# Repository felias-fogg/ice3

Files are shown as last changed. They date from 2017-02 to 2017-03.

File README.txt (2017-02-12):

This Arduino sketch implements a cache thermometer, as for example
used in these geocaches:
- http://coord.info/GC3NEYY
- http://coord.info/GC47429
- http://coord.info/GC36NCQ

The generic hardware is sketched in the files open-V2-board.tiff and 
open-V2-plan.tiff. For the particular case of a thermometer, a DS18S20
and a LED is added in the prototyping section of the board. 

In order to compile and burn the sketch to the ATtiny84, one has to
make a few additions and modifications to the Arduino IDE and one
either has to use an existing UNO board as an ISP programmer or one
has to buy such a programmer, e.g., a USBtinyISP, see
http://www.amazon.com/HOSSEN%C2%AE-USBtinyISP-Programmer-Arduino-Bootloader/dp/B00CR9UGZQ/ref=sr_1_5.

First of all, one needs to extend the Arduino IDE to deal with
ATtiny processors. This is described in detail here:
http://hlt.media.mit.edu/?p=1695.

In order to compile the ice3 sketch, you need the OneWire
library. Note that the original library will not work here, because we
want the ATtiny to run with 1MHz. So download and install this library instead: https://github.com/felias-fogg/OneWire.

Now you should be able to compile the sketch. Please select ATtiny84
(internal 1 MHz) before doing so. By the way, if the ATtiny has been
used before, perhaps some fuses have to be set. In particular the one
for the processor speed. This can be done by pretending to upload the
bootloader. If it is a brand new processor or the one from an existing
ice3 board, the fuses will have been set to 1 MHz already.

Finally, you should be able to burn the program to the chip. Before
doing so remove the jumper that provides power to the board.  Plug the
6-pin ISP connector to the PCB such that the nose of the connector is
oriented towards the battery. Select the right programmer in the Tools
menu and select also the right serial port. Then you can use the
upload button to burn the program to the chip.

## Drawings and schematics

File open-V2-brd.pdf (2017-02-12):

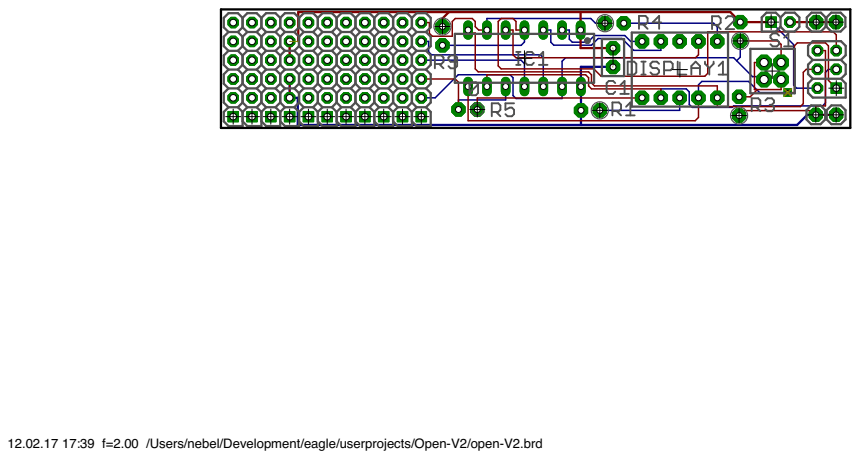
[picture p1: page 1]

12.02.17 17:39 f=2.00 /Users/nebel/Development/eagle/userprojects/Open-V2/open-V2.brd

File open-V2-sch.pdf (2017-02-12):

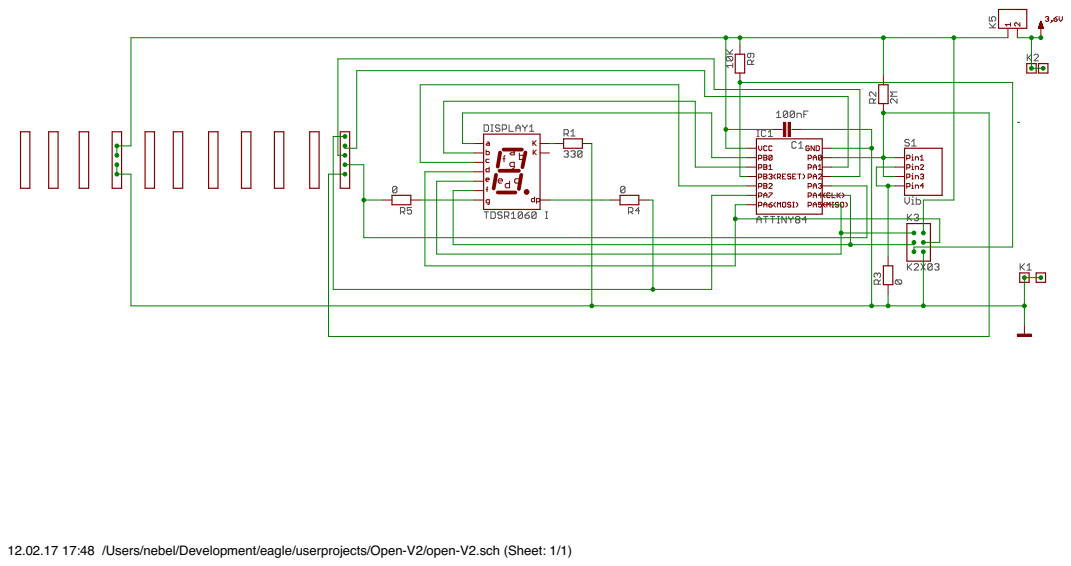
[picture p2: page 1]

12.02.17 17:48 /Users/nebel/Development/eagle/userprojects/Open-V2/open-V2.sch (Sheet: 1/1)

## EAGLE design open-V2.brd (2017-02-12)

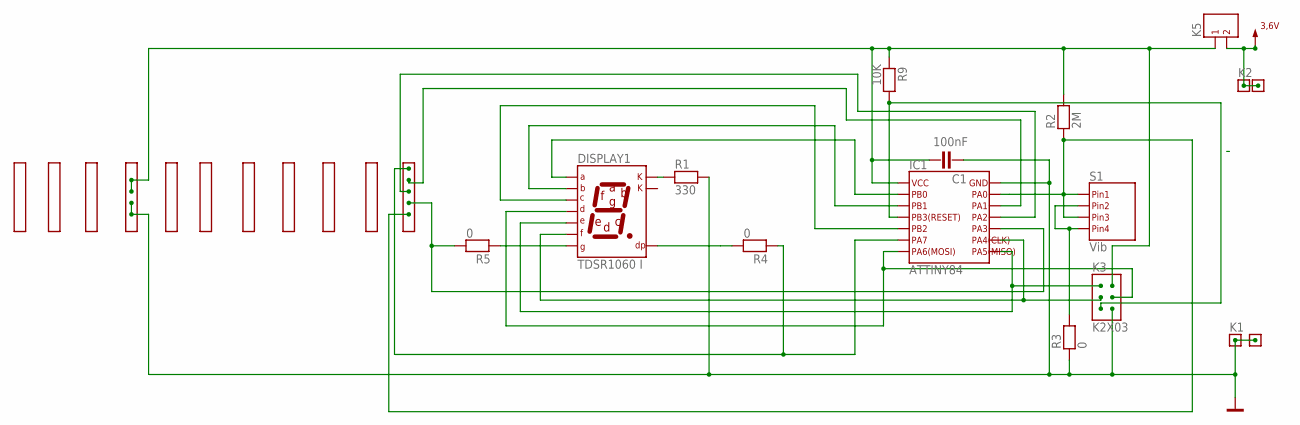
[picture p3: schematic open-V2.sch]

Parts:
C1: 100nF; C1
DISPLAY1: TDSR1060 I; DISPLAY1
IC1: ATTINY84; IC1
K1: K1
K2: K2
K3: K2X03; K3
K4: K4
K5: K5
K6: K6
K7: K7
K8: K8
K9: K9
K10: K10
K11: K11
K12: K12
K13: K13
K14: K14
K15: K15
K16: K16
K18: K18
R1: 330; R1
R2: 2M; R2
R3: 0; R3
R4: 0; R4
R5: 0; R5
R9: 10K; R9
S1: Vib; S1

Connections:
1: DISPLAY1.1 (G), R5.1
3,6V: K2.1, K5.2, K18.1
A: DISPLAY1.10 (A), IC1.2 (PB0)
B: DISPLAY1.9 (B), IC1.3 (PB1)
C: DISPLAY1.7 (C), IC1.5 (PB2)
D/MOSI: DISPLAY1.5 (D), IC1.7 (PA6(MOSI)), K3.4
DP: DISPLAY1.6 (DP), R4.2
E/MISO: DISPLAY1.4 (E), IC1.8 (PA5(MISO)), K3.1
F/CLK: DISPLAY1.2 (F), IC1.9 (PA4(CLK)), K3.3
G: IC1.10 (PA3), K10.3, R5.2
GND: C1.1, IC1.14 (GND), K1.1, K3.6, K13.2, K13.3, K16.1, R1.2, R3.1
K: DISPLAY1.3 (K), R1.1
PA0: IC1.13 (PA0), K10.2, R2.1, S1.1 (PIN1), S1.3 (PIN3)
PA1: IC1.12 (PA1), K10.5
PA2: IC1.11 (PA2), K10.4
PA7: IC1.6 (PA7), K10.6, R4.1
RST: IC1.4 (PB3(RESET)), K3.5, R9.2
SIG$25: R3.2, S1.2 (PIN2), S1.4 (PIN4)
VCC: C1.2, IC1.1 (VCC), K3.2, K5.1, K13.4, K13.5, R2.2, R9.1

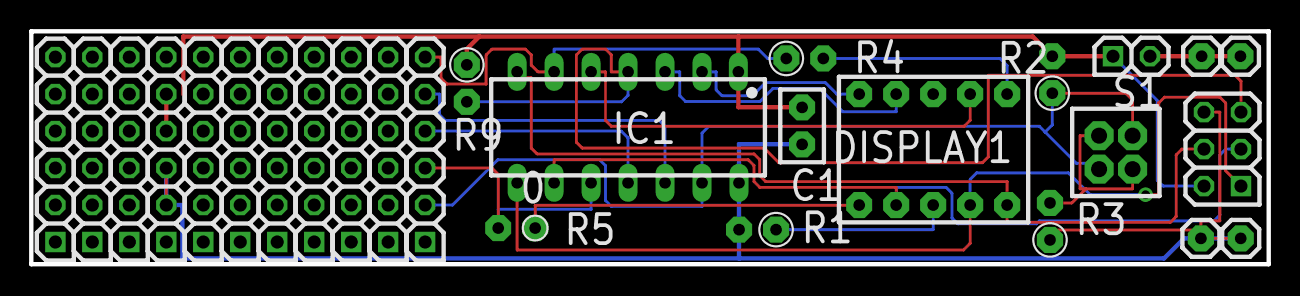
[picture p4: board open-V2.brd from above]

Board: 2 copper layers, 85.0 x 16.0 mm, 27 parts (0 on the bottom side), 19 nets.

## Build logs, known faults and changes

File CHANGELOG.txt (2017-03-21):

Version 3 - 22.8.2013
	- Version that is working in the Cache "Geocache on the Rocks"

Version 3.1 - 5.10.2013
       - new flag for switching between Celsius and Fahrenheit in EEPROM

Version 3.4 - 21.3.1017
      - added  __attribute__((used)) to wdt_init

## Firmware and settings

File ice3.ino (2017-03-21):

// -*- c++ -*-
// Developed on a Pro Mini, deployed on an Attiny84

#include <avr/pgmspace.h>
#include <avr/wdt.h>
#include <avr/sleep.h>
#include <avr/eeprom.h>
#include <OneWire.h>

// CHANGE NEXT LINES! ************************************************
const char show_string[] = "N 44# 43.541  W 63# 44.270    ";
#define DEFAULT_SYSTEM_CELCIUS 0xFF // 0xFF means celcius is default 
#define TEMP_THRESH 4.0 // degrees Celcius
// END OF CHANGE *********************************************************

#define VERSION "Version 3.4" 

uint8_t celcius[1] EEMEM; // flag for celcius or fahrenheit (default celcius = 0xFF)
uint8_t coords[30] EEMEM; // coord string - will be loaded from default show_string

#define DEBUGVOLT 1
#define DEBUGWAIT
#define COORDSHOW 6 // show coords this number of times
#define PCBVERSION 3 // can be 0: no DS18S20, 1 or 2 : open-vX board, 3: open-v2
#define ERROR_THRESH 5 // after this many errors, we give up

/* display times */
#define DISPLAY_ON_MSECS 800 // msecs on
#define DISPLAY_OFF_MSECS 300 // msecs off
#define LONGDEEPSLEEP_SECS 40 // have a deep sleep after displaying coords
#define SHORTDEEPSLEEP_SECS 10 // after batt lo
#define MAX_NOCHANGE_MSECS 240000UL // msecs without change leads to sleep
#define MAX_ACTIVE_MSECS  2400000UL // 30 minutes max on!
#define MAX_WAKEUP_MSECS 20000UL // msecs to wake up!
#define MIN_BUMPS 4 // minimum of 4 bumps before complete wakeup
#define READY_MAX 3 // show temp after reaching threshold
#define LOWVOLT_WARN 2.9
#define LOWVOLT_ERROR 2.6 // below this, we only show "Lo Batt"
#define LOWBATTSHOW_MSECS 30000UL // show Low-Batt message for this number of msecs


#if PCBVERSION == 3 // same version of board as 2, but LED and DS18S20 switched
#define DS18S20 2
#define VPINSEGG 7
#define VPINLED 1
#define VOLTOFFSET 0.0
#define TEMPTOLERANCE 0.0
#endif
#if PCBVERSION == 2 // new version of board
#define DS18S20 1
#define VPINSEGG 7
#define VPINLED 2
#define VOLTOFFSET 0.0
#define TEMPTOLERANCE 0.0
#endif
#if PCBVERSION == 1 // old version of board
#define DS18S20 1
#define VPINSEGG 2
#define VPINLED 7
#define VOLTOFFSET 0.0
#define TEMPTOLERANCE 0.0
#endif
#if PCBVERSION == 0 // PCB without temperature sensor
#define VPINLED 7
#define VPINSEGG 1
#define VOLTOFFSET -0.2
// needed for calibrating the internal temp sensor
#define TOS -244
#define BANDGAPVAR 5
#define TEMPSCALE 0.7068
#define TEMPTOLERANCE 2.0
#endif

#ifdef __AVR_ATmega328P__
#define POFF 2
#define ATMEGA 1
#define T1_vect TIMER1_OVF_vect
#define PCINT_vect PCINT1_vect
#else
#define POFF 0
#define ATTINY 1
#define T1_vect TIM1_OVF_vect
#define PCINT_vect PCINT0_vect
#endif


/* Connections auf open-v1 (proto area to the left)
   Put in: R1, R2, R3, R9, C1, ISP, jumper connector
   Put in: IC1 Punkt/Kerbe Richtung ISP-Stecker
   Put in: Display D1 with dot towards IC
   Brücke von R4 unten nach erste Reihe Pin 3/4
   Connection from 5/6 to middle pin of DS1820
   4,7K from pin 2 of DS1820 to VCC
   Pin 1 of DS1820 to GND, pin 3 to VCC
*/
/* Display
   Seg	AVR-Pin Ard#(Attiny) Ard#(ProMini)
   a(10) -  PA6   6          8
   b(9)  -  PA5   5          7
   c(7)  -  PA4   4          6
   d(5)  -  PB0  10         12
   e(4)  -  PB1   9         11
   f(2)  -  PB2   8         10
   g(1)  -  PA2   2          4
   dp(6) -  PA3   3          5
*/
/* Other connections
   Bez          Ard#(Attikny) Ard#(ProMini)
   Vib             0             2
   LED             7             9
   1Wire           1             3
*/

/* Connections Open-v2:
   Seg	AVR-Pin Ard#(Attiny) Ard#(ProMini)
   a(10) -  PA6   6          8
   b(9)  -  PA5   5          7
   c(7)  -  PA4   4          6
   d(5)  -  PB0  10         12
   e(4)  -  PB1   9         11
   f(2)  -  PB2   8         10
   g(1)  -  PA7   7          9
   dp(6) -  PA3   3          5

   ID          Ard#(Attiny) Ard#(ProMini)
   Vib             0             2
   LED             2             4
   1Wire           1             3

   R1: 330 Ohm
   R2: 3,3 MOhm
   R3: short
   R4: short
   R5: short
   R9: 10K
   C1: 100nF
   DS1820 Pin1: GND
   DS1820 Pin2: 4,7 kOhm to Vcc and connect to D1 (PA1) = Pin5 of connector
   DS1820 Pin3: Vcc
   LED Anode to Pin4 of connector
   
*/

#define LED (VPINLED+POFF)
#define ONE_WIRE_BUS (DS18S20+POFF) 



#ifdef DS18S20 // only if there is a DS18S20, we need the library!
// Setup a oneWire instance to communicate with any OneWire devices
OneWire ds(ONE_WIRE_BUS);
uint8_t dsdata[12];
uint8_t dsaddr[8];
#endif

float goal_temp = TEMP_THRESH;
float last_min_temp = 100.0;
#define CRC_ERROR -127.0
#define NOT_PRESENT_ERROR -126.0


// LCD segment definitions. 
// These will need to be changed depending on the 
// wiring of your output port to the segements.
#define SEGa (1<<(6+POFF))
#define SEGb (1<<(5+POFF))
#define SEGc (1<<(4+POFF))
#define SEGd (1<<(10+POFF))
#define SEGe (1<<(9+POFF))
#define SEGf (1<<(8+POFF))
#define SEGg (1<<(VPINSEGG+POFF))
#define SEGdp (1<<(3+POFF))

const uint8_t lcd_seg[] =
  { (6+POFF), (5+POFF), (4+POFF), (10+POFF), (9+POFF), (8+POFF), (VPINSEGG+POFF), (3+POFF) };


// LCD Character Generator 
// Change these defines as needed to make new characters.

const uint16_t ascii_gen[] = {
  0, // " "
  0, // "!"
  SEGf+SEGb, // """
  SEGa+SEGb+SEGg+SEGf, // "#" - display degree symbol 
  0, // "$"
  0, // "%"
  0, // "&"
  SEGb, // "'"
  SEGa+SEGd+SEGe+SEGf, // "("
  SEGa+SEGb+SEGc+SEGd, // ")"
  0, // "*"
  0, // "+"
  SEGc, // ","
  SEGg, // "-"
  SEGdp, // "."
  0, // "/"
  SEGa+SEGb+SEGc+SEGd+SEGe+SEGf,   // Displays "0"
  SEGb+SEGc,           // Displays "1"
  SEGa+SEGb+SEGd+SEGe+SEGg,     // Displays "2"
  SEGa+SEGb+SEGc+SEGd+SEGg,     // Displays "3"
  SEGb+SEGc+SEGf+SEGg,       // Displays "4"
  SEGa+SEGc+SEGd+SEGf+SEGg,     // Displays "5"
  SEGa+SEGc+SEGd+SEGe+SEGf+SEGg,   // Displays "6"
  SEGa+SEGb+SEGc,         // Displays "7"
  SEGa+SEGb+SEGc+SEGd+SEGe+SEGf+SEGg, // Displays "8"
  SEGa+SEGb+SEGc+SEGd+SEGf+SEGg,   // Displays "9"
  0, // ":"
  0, // ";"
  SEGd+SEGe+SEGg, // "<"
  SEGg+SEGd, // "="
  SEGg+SEGc+SEGd, // ">"
  SEGa+SEGb+SEGg+SEGe, // "?"
  0, // "@"
  SEGa+SEGb+SEGc+SEGe+SEGf+SEGg, // "A"
  SEGc+SEGd+SEGe+SEGf+SEGg,   // "b"
  SEGa+SEGd+SEGe+SEGf,     // "C"
  SEGb+SEGc+SEGd+SEGe+SEGg,   // "d"
  SEGa+SEGd+SEGe+SEGf+SEGg,   //  "E"
  SEGa+SEGe+SEGf+SEGg,     //  "F"   
  SEGa+SEGc+SEGd+SEGe+SEGf,   //  "G"
  SEGc+SEGe+SEGf+SEGg,     //  "h"
  SEGf+SEGe,         //  "I"
  SEGb+SEGc+SEGd+SEGe,     //  "J"
  SEGa+SEGc+SEGe+SEGf+SEGg,   //  "k"
  SEGd+SEGe+SEGf,       //  "L"
  SEGa+SEGc+SEGe,       //  "M"
  SEGc+SEGe+SEGf+SEGb+SEGa,       //  "n"
  SEGc+SEGd+SEGe+SEGg,     //  "o"
  SEGa+SEGb+SEGe+SEGf+SEGg,   //  "P"
  SEGa+SEGb+SEGd+SEGf+SEGg,   //  "q"
  SEGe+SEGg,         //  "r"
  SEGc+SEGf+SEGg,   //  "S"
  SEGd+SEGe+SEGf+SEGg,     //  "t"
  SEGb+SEGc+SEGd+SEGe+SEGf,   //  "U"
  SEGc+SEGd+SEGe,       //  "v"
  SEGb+SEGd+SEGf,       //  "W"
  SEGb+SEGc+SEGe+SEGf+SEGg,   //  "X"
  SEGb+SEGc+SEGd+SEGf+SEGg,   //  "Y"
  SEGa+SEGb+SEGd+SEGe+SEGg,    //  "Z"
};
#define LASTCHAR 'Z'

/* states */
#define DEEPSLEEP_STATE 0
#define SLEEP_STATE 1
#define WAKEUP_STATE 2
#define MEASURE_STATE 3
#define BATTCHECK_STATE 4
#define BATTLOW_STATE 5
#define GOTO_SLEEP_STATE 6
#define READY_STATE 7
#define SHOW_STATE 8
#define ERROR_STATE 9

int readycnt = 0;
int errcnt = 0;
int errnum = 0;
int bumpcnt = 1; // when we start, there was already one bump!
unsigned long now = 0;
unsigned long last_now = 0;
unsigned long waittime = 0;
int circx = 0;
float volt;
boolean lowvolt = false;
int deepsleep_secs;

int state = WAKEUP_STATE; // when we start, we have been woken up
int last_state = ERROR_STATE+1;

/* blink modes */
#define NOBLINK 0
#define EXTERNBLINK 1
#define SLOWBLINK 2
#define FASTBLINK 3
#define VERYFASTBLINK 4
/* flag for LED blinking */
volatile uint8_t blink = EXTERNBLINK;

/* flag that signals that we should count instead of resetting */
volatile bool wdt_count = false;

/* bump flag */
volatile bool bumps = false;

/* interrupt routine to drive display */
/* variables for display driver */
int csegix = 0; // current segment index
long cmask = 0;
volatile unsigned char dispchar =  ' ';


ISR(T1_vect)
{
  TCNT1 = 0xFFFF-40; // with 8MHz: 156;
  digitalWrite(lcd_seg[csegix],LOW);
  if (++csegix == 8) {
    csegix = 0;
  }
  if (csegix < 7) {
    if (1<<lcd_seg[csegix]&ascii_gen[(0x7F&dispchar)-' ']) {
      digitalWrite(lcd_seg[csegix],HIGH);
    }
  } else {
    if (dispchar&0x80 || dispchar == '.') 
      digitalWrite(lcd_seg[csegix],HIGH); // first bit = dp
  }
  switch (blink) {
  case NOBLINK: digitalWrite(LED,LOW); break;
  case SLOWBLINK: if ((millis()%4000) < 100) digitalWrite(LED,HIGH);
    else digitalWrite(LED,LOW); break;
  case FASTBLINK: if ((millis()%500) < 150) digitalWrite(LED,HIGH);
    else digitalWrite(LED,LOW); break;
  case VERYFASTBLINK: if ((millis()%250) < 50) digitalWrite(LED,HIGH);
    else digitalWrite(LED,LOW); break;
  }
}

ISR(WDT_vect)
{
  if (wdt_count) WDTCSR |= (1<<WDIE); // re-enable watchdog interrupt
}

ISR(PCINT_vect)
{
  bumps = true;
}

void startTimerOne(void) {
  TCCR1A = 0;
  TCCR1B = (1<<CS11|1<<CS10); //  prescaler = 64
  TCCR1C = 0;
  TIMSK1 = (1<<TOIE1);
  TCNT1 = 0xFFFF-200;
}

void stopTimerOne(void) {
  TIMSK1 = 0;
}


void idleDelay(int msecs)
{
  unsigned long start;

  start = millis();
  while (millis() - start < msecs) {
    set_sleep_mode(SLEEP_MODE_IDLE);
    sleep_mode();
  }
}

void displayString(char *mess)
{
  while (*mess) {
    dispchar = *mess++;
    idleDelay(DISPLAY_ON_MSECS);
    dispchar = ' ';
    idleDelay(DISPLAY_OFF_MSECS);
  }
}

void displayCoords() 
{
  char buf[2];
  int i;
  buf[1] = '\0';
  do {
    buf[0] = eeprom_read_byte(&coords[i++]);
    if (buf[0]) displayString(buf);
  } while (buf[0]);
}


void displayFloat(float num, bool dp) 
{
  char buf[10];
  int i=0;
  bool zero = false;
  int d = 1000;
  int tmp;
  int inum = round(num*10);
#ifdef ATMEGA
  Serial.print(F("num:  "));
  Serial.println(num,2);
  Serial.print(F("inum: "));
  Serial.println(inum);
#endif
  if (inum < 0) {
    buf[0] = '-';
    inum = -inum;
    i++;
  }
  if (inum > 6000) {
    buf[0] = '\0'; 
    errcnt++;
    errnum=9;
  } else {
    while (d > 0) {
      tmp = inum/d;
      if (tmp > 0) {
	buf[i++] = tmp + '0';
	zero = true;
      } else if (zero || d == 10 || (!dp && d == 100 && num > 0)) {
	buf[i++] = '0';
	zero = true;
      }
      if (d == 10 && dp) buf[i-1] |= 0x80;
      inum -= (d*tmp);
      d = d/10;
      if (!dp && d == 1) d = 0;
    }
    buf[i] = '\0';
  }
  displayString(buf);
  // idleDelay(2*DISPLAY_ON_MSECS);
}
    
void displayTemp(float temp) 
{
  float showtemp;
  
  if (eeprom_read_byte(&celcius[0]) == 0) 
    showtemp = temp*1.8+32;
  else
    showtemp = temp;
  
#ifdef DS18S20
  displayFloat(showtemp,true);
#else
  displayFloat(showtemp,false);
#endif
  
  if (eeprom_read_byte(&celcius[0]) == 0) 
    displayString("#F");
  else
    displayString("#C");

}

void enablePinChangeIRQ(void) 
{
#ifdef ATMEGA
  PCICR |= (1<<PCIE1); // allow for PCINT on PCINT8-14
  PCMSK1 |= (1<<PCINT8); // on pin PC0 = ADC0 = PCINT8 = analog0 = dig. pin 14
#endif 
#ifdef ATTINY
  GIMSK |= (1<<PCIE0);  // allow for PCINT on PA0-PA7
  PCMSK0 |= (1<<PCINT0); // on pin PA0 = ADC0 = analog0 = dig. pin 0
#endif
}

void disablePinChangeIRQ(void)
{
#ifdef ATMEGA
  PCICR &= ~(1<<PCIE1);
#endif 
#ifdef ATTINY
  GIMSK &= ~(1<<PCIE0);  
#endif
}

void initIO(void) {
  int i;
  for (i=0;i<8;i++) {
    pinMode(lcd_seg[i],OUTPUT);
    digitalWrite(lcd_seg[i],LOW);
  }
  pinMode(LED,OUTPUT);
  digitalWrite(LED,LOW);
}

void IOoff(void) {
  int i;
  blink = NOBLINK;
  for (i=0;i<8;i++) {
    digitalWrite(lcd_seg[i],LOW);
  }
  digitalWrite(LED,LOW);
  ADCSRA &= ~(1<<ADEN); // switch off ADC
}

void setupIO(void)
{
  initIO();
  startTimerOne();
  enablePinChangeIRQ();
}


#ifdef ATMEGA
// function to return free mem
int freeRam(void)
{
  extern unsigned int __heap_start;
  extern void *__brkval;

  int free_memory;
  int stack_here;

  if (__brkval == 0)
    free_memory = (int) &stack_here - (int) &__heap_start;
  else
    free_memory = (int) &stack_here - (int) __brkval; 

  return (free_memory);
}

#endif

#ifdef DS18S20
void setupDS18S20(void) 
{
  if (!ds.search(dsaddr)) { // no device 
    errnum = 1;
    state = ERROR_STATE;
#ifdef ATMEGA
    Serial.println(F("No device present"));
#endif
    return;
  }
  if (OneWire::crc8(dsaddr, 7) != dsaddr[7]) {
    errnum = 2;
    state = ERROR_STATE;
#ifdef ATMEGA
    Serial.println("CRC is not valid!");
#endif
    return;
  }
  if (dsaddr[0] != 0x10) { // not a DS18S20!
    errnum = 3;
    state = ERROR_STATE;
#ifdef ATMEGA
    Serial.println("Not the right chip!");
#endif
    return;
  }
#ifdef ATMEGA
  Serial.println(F("  DS18S20 initializied"));
#endif
}
#endif

float readVoltage(void)
{
  int reading;
  float result;

  ADCSRA |= _BV(ADEN); // switch on ADC
#ifdef ATMEGA
  ADMUX = _BV(REFS0) | _BV(MUX3) | _BV(MUX2) | _BV(MUX1);
#else
  ADMUX = _BV(MUX5) | _BV(MUX0);
#endif
  delay(100); // Wait for Vref to settle
  ADCSRA |= _BV(ADSC); // Convert
  while (bit_is_set(ADCSRA,ADSC));
  reading = ADCL;
  reading |= ADCH<<8;
  result = 1126.4 / reading; // Back-calculate AVcc in mV
  result = result;
  // correction:
  if (result > 4.5) result = result - (result - 4.5)*0.17;
  else result = result + (4.5 - result)*0.05;
  result += VOLTOFFSET;

#ifdef ATMEGA
  Serial.print(F("Raw voltage: "));
  Serial.println(reading);
  Serial.print(F("Voltage:  "));
  Serial.println(result,2);
#endif
#ifdef DS18S20
  ADCSRA &= ~(_BV(ADEN));
#endif
  return result;
}

#ifndef DS18S20
float readIntTemp(void)
{
  int reading;
  float result;

#ifdef ATMEGA
  ADMUX = _BV(REFS0) | _BV(MUX3);
#else
  ADMUX =  _BV(REFS1) | _BV(MUX5) | _BV(MUX1);
#endif

  delay(20); // Wait for Vref to settle
  ADCSRA |= _BV(ADSC); // Convert
  while (bit_is_set(ADCSRA,ADSC));
  reading = ADCL;
  reading |= ADCH<<8;
  result = reading;
  
#ifdef ATMEGA
  Serial.print(F("Raw int. temp.: "));
  Serial.println(reading);
  //  Serial.print(F("Int. temp.:  "));
  //  Serial.println(result,2);
#endif
  return result;
}
#endif

float readTemp(void) 
{
#ifdef DS18S20
  bool present;
  ds.reset();
  ds.select(dsaddr);
  ds.write(0x44,1); // parasite power
  idleDelay(1000);
  present = ds.reset();
  if (!present) return NOT_PRESENT_ERROR;
  ds.select(dsaddr);
  ds.write(0xBE);
  for (int i=0; i<9; i++) dsdata[i] = ds.read();
  if (OneWire::crc8(dsdata, 8) != dsdata[8]) {
    return CRC_ERROR;
  }
  int raw = (dsdata[1] << 8) | dsdata[0];
  raw = raw << 3;
  if (dsdata[7] == 0x10) raw = (raw & 0xFFF0) + 12 - dsdata[6];
  return (float)raw/16.0;
#else
  return(round(TEMPSCALE*(readIntTemp()+TOS+((volt-3.5)*BANDGAPVAR))));
#endif
}


#ifdef ATTINY
// This does not do anything under Arduino, since the bootloader will take care 
// but when running standalone it guards against reset loops caused by
// watchdog resets. 
// Note: The ordinary bootloader appears to be too slow at least when running
// at 8MHz. It creates endless watch-dog reset loops!
void wdt_init(void) __attribute__((naked)) __attribute__((section(".init3"))) __attribute__((used));
void wdt_init(void)
{
  MCUSR = 0;
  wdt_disable();
  return;
} 
#endif


void setup()
{
  int i;
#ifdef ATMEGA
  Serial.begin(19200);
  Serial.println(F("Coordinate thermometer V2.0\n"));
  Serial.println(F("Setup start..."));
  Serial.println(F(" I/O..."));
#endif
  setupIO();
#ifdef DS18S20
#ifdef ATMEGA
  Serial.println(F(" 1wire Dallas..."));
#endif
  setupDS18S20();
#endif
#ifdef ATMEGA
  Serial.println(F("...setup done"));
  Serial.print(F("Free mem: "));
  Serial.println(freeRam(),DEC);
#endif
#ifdef ATMEGA
  if (eeprom_read_byte(&coords[0]) == 0xFF) {
    Serial.println(F("Initialzing Coords"));
  } else {
    Serial.println(F("Coords already loaded in EEPROM"));
  }
#endif
  blink = EXTERNBLINK;
  if (eeprom_read_byte(&coords[0]) == 0xFF) {
    digitalWrite(LED,HIGH);
    i = 0;
    do {
      eeprom_write_byte(&coords[i],show_string[i]);
    } while (show_string[i++]);
    eeprom_write_byte(&celcius[0],DEFAULT_SYSTEM_CELCIUS);
    idleDelay(4000);
    digitalWrite(LED,LOW);
  }
  blink = NOBLINK;
#ifdef DS18S20
  ADCSRA &= ~(_BV(ADEN)); // switch off ADC
#endif
}

void loop()
{
  int sleep,i;
  unsigned long last_period = 0;
  char errmess[] = "ERROR0  ";
  float temp, inttemp;
  float start_temp;


  last_now = now;
  now = millis();
  if (last_now != 0) last_period = (now - last_now);
#ifdef ATMEGA
  if (last_state != state) {
    switch (state) {
    case DEEPSLEEP_STATE: Serial.println(F("DEEPSLEEP")); break;
    case SLEEP_STATE: Serial.println(F("SLEEP")); break;
    case GOTO_SLEEP_STATE: Serial.println(F("GOTO_SLEEP")); break;
    case WAKEUP_STATE: Serial.println(F("WAKEUP")); break;
    case BATTCHECK_STATE: Serial.println(F("BATTCHECK")); break;
    case BATTLOW_STATE: Serial.println(F("BATTLOW")); break;
    case MEASURE_STATE: Serial.println(F("MEASURE")); break;
    case READY_STATE: Serial.println(F("READY")); break;
    case SHOW_STATE: Serial.println(F("SHOW")); break;
    case ERROR_STATE: Serial.println(F("ERROR")); break;
    default: Serial.println(F("ILLEGAL")); break;
    }
    last_state = state;
  }
#endif
  
  if (errcnt >= ERROR_THRESH) {
    state = ERROR_STATE;
  }

  if (millis() > MAX_ACTIVE_MSECS && state != DEEPSLEEP_STATE && state != SLEEP_STATE) {
    deepsleep_secs = SHORTDEEPSLEEP_SECS;
    state = DEEPSLEEP_STATE;
  }

  switch (state) {
    
  case DEEPSLEEP_STATE: // do not respond for some time (deepsleep_secs)
    digitalWrite(LED,HIGH);
    idleDelay(50);
    volt = readVoltage();
    digitalWrite(LED,LOW);
    wdt_disable();
    displayString("BATT ");
    displayFloat(volt,true);
    idleDelay(DISPLAY_ON_MSECS);
    displayString("VOLT");
    idleDelay(DISPLAY_ON_MSECS*2);
    displayString("BYE");
    stopTimerOne();
    disablePinChangeIRQ();
    IOoff();
    wdt_count = true;
    wdt_enable(WDTO_8S);
    WDTCSR |= (1<<WDIE); // enable WDT interrupt instead of reset
    sleep = deepsleep_secs;
    while (sleep > 0) {
      set_sleep_mode(SLEEP_MODE_PWR_DOWN);
      sleep_mode();
      sleep = sleep - 8;
    }
    wdt_disable();
    wdt_count = false;
    state = SLEEP_STATE;
    break;

  case SLEEP_STATE: // disable everything and arm the pin change IRQ
    wdt_disable();
    stopTimerOne();
    IOoff();
    enablePinChangeIRQ();
    idleDelay(500);
    bumps = false;
    set_sleep_mode(SLEEP_MODE_PWR_DOWN);
    sleep_mode();
    // we return here after a pin change interrupt!
    WDTCSR &= ~(1<<WDIE); // disable WDT interrupt -> reset
#ifdef ATMEGA
    Serial.println(F("Wakeup after sleep"));
#endif
    wdt_enable(WDTO_15MS); // after 15 milli seconds
    delay(100); // we should self reset in this time!
    state = ERROR_STATE; // if no reset, goto error state
    errnum = 4;
    break;
    /*
#endif
    */

  case WAKEUP_STATE: // the state after waking up triggered by the vib IRQ
    blink = EXTERNBLINK;
    waittime += last_period;
    if (waittime > MAX_WAKEUP_MSECS) {
      waittime = 0;
      state = SLEEP_STATE;
      break;
    }
    if (bumpcnt >= MIN_BUMPS) {
      waittime = 0;
      state = BATTCHECK_STATE;
      break;
    }
    if (bumps) {
#ifdef ATMEGA
      Serial.println(F("bump"));
#endif
      bumpcnt++;
      digitalWrite(LED,HIGH);
      idleDelay(50);
      bumps = false;
      digitalWrite(LED,LOW);
      idleDelay(100);
    }
    idleDelay(50);
    break;

  case BATTCHECK_STATE:
    digitalWrite(LED,HIGH);
    idleDelay(50);
    volt = readVoltage();
    digitalWrite(LED,LOW);
    //    displayString("BATT ");
    //    displayFloat(volt,true);
    //    idleDelay(2*DISPLAY_ON_MSECS);
#ifdef DEBUGVOLT
    state = MEASURE_STATE;
#else
    if (round(volt*10)/10.0 < LOWVOLT_ERROR) state = BATTLOW_STATE;
    else {
      state = MEASURE_STATE;
      lowvolt = (round(volt*10)/10.0 < LOWVOLT_WARN);
    }
#endif
    start_temp = readTemp();
#ifdef ATMEGA
    Serial.print(F("Current temp: "));
    Serial.println(start_temp,2);
#endif
    if (start_temp - goal_temp > 10.0) {
      goal_temp = start_temp - 10.0;
    }
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
